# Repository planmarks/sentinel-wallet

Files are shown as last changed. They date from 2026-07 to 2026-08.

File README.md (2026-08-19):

<div align="center">

# 🛡️ Sentinel Hardware Wallet

### Your keys and coins kept offline, signed offline, on a device you hold in your hand.







*A pocket-sized, open-source cold wallet for 14 blockchains.*

</div>

---

> ⚠️ **Status:** Firmware version `1.0.0`. This is a hobbyist / educational hardware-wallet project,
> not a certified secure product. Please read the [Security Model & Honest Limitations](#-security-model--honest-limitations)
> section before storing meaningful funds.

---

## 📖 What It Is

A cold wallet keeps the secret keys that control your crypto **offline**, away from any
internet-connected computer. Sentinel follows that model:

- **Keys are born on the device.** A BIP39 recovery phrase (12/18/24 words) is generated from the
  chip's hardware random number generator — or you can restore an existing phrase.
- **Keys stay on the device.** The seed is encrypted and written to the chip's flash. It only ever
  exists in plaintext in RAM while the wallet is unlocked, and it's wiped from RAM the moment you lock.
- **The device only signs what you approve.** The companion app builds a transaction and sends it
  over. Sentinel shows you the recipients and the fee on its own screen, and it won't sign until you
  press and hold the confirm button.
- **It works air-gapped.** USB and Bluetooth are just transports for passing transaction data back
  and forth; the signing itself is fully offline, and Bluetooth is **off by default**.

**Hardware target:** Seeed XIAO ESP32-C5 · Arduino-ESP32 core 3.3.5+
**Display:** SSD1306/SSD1315 128×64 I²C OLED
**Interface:** 6 buttons (Up / Down / OK / Back / Left / Right), USB serial, optional BLE

---

## 🪙 Supported Cryptocurrencies

Sentinel supports a wide range of chains across multiple cryptographic families. Like a real
hardware wallet, **EVM chains and tokens all sign through a single "Ethereum" engine**, and SPL /
TRC-20 tokens sign through their parent chain — so the list of *assets* you can hold is much larger
than the list of on-device menu entries.

### Bitcoin & UTXO chains

| Coin | Ticker | Curve | Derivation | Address type |
|---|---|---|---|---|
| Bitcoin | BTC | secp256k1 | BIP84 `m/84'/0'` | Native SegWit (bech32) |
| Litecoin | LTC | secp256k1 | BIP84 `m/84'/2'` | Native SegWit (`ltc…`) |
| Dogecoin | DOGE | secp256k1 | BIP44 `m/44'/3'` | P2PKH |
| Dash | DASH | secp256k1 | BIP44 `m/44'/5'` | P2PKH |
| DigiByte | DGB | secp256k1 | BIP84 `m/84'/20'` | Native SegWit (`dgb…`) |
| Ravencoin | RVN | secp256k1 | BIP44 `m/44'/175'` | P2PKH |
| Bitcoin Cash | BCH | secp256k1 | `m/44'/145'` | CashAddr (SIGHASH_FORKID) |

Bitcoin (and other PSBT chains) support full **PSBT** signing with itemized output review.

### Ethereum & EVM chains

The **Ethereum** engine (`secp256k1`, BIP44 `m/44'/60'`, EIP-1559) signs for Ethereum **and every
EVM-compatible chain and ERC-20 token** the companion app knows about. The correct label is derived
from the transaction payload itself (chain ID for native transfers, contract address for tokens).

- **Ethereum (ETH)** and ERC-20 tokens such as **USDT** and **USDC**
- EVM chains routed through the same engine include:
  **BNB** Smart Chain, **Avalanche** (AVAX), **Polygon** (POL), **Base**, **Optimism** (OP),
  **Arbitrum** (ARB), **Cronos** (CRO), **Fantom** (FTM), **Ethereum Classic** (ETC), **Linea**,
  **Celo**, **Mantle** (MNT), **Flare** (FLR), **XDC**, **KuCoin Chain** (KCS), **X Layer** (OKB),
  **Filecoin EVM** (FILEVM), **BitTorrent Chain** (BTT), **IOTA EVM**, **Sonic** (S),
  **Kaia** (KAIA), **Hyperliquid** (HYPE), **Monad** (MON), and others (XTZ, XPL, M).

> New EVM chains and ERC-20 tokens generally need **no firmware change** — they're added on the app
> side, since they all share Ethereum's keys, addresses, and signing.

### Solana & SPL tokens

| Coin | Ticker | Curve | Derivation |
|---|---|---|---|
| Solana | SOL | ed25519 | SLIP-0010 `m/44'/501'` |

Solana transfers are decoded and itemized for review; **SPL tokens** sign through the same Solana
engine.

### Cosmos ecosystem

All Cosmos-SDK chains use `secp256k1`, `m/44'/118'`, and bech32 addresses (differing only by prefix):

| Coin | Ticker | Address prefix |
|---|---|---|
| Cosmos Hub | ATOM | `cosmos…` |
| dYdX | DYDX | `dydx…` |
| Axelar | AXL | `axelar…` |
| Babylon | BABY | `bbn…` |
| Celestia | TIA | `celestia…` |

### Other Layer-1 networks

| Coin | Ticker | Curve | Derivation | Notes |
|---|---|---|---|---|
| XRP Ledger | XRP | secp256k1 | `m/44'/144'` | base58check |
| Stellar | XLM | ed25519 | SLIP-0010 `m/44'/148'` | payments itemized |
| Cardano | ADA | BIP32-Ed25519 (Icarus) | `m/1852'/1815'` | Blake2b, staking support |
| Tron | TRX | secp256k1 | `m/44'/195'` | base58check (`T…`) |
| Tether on Tron | USDT (TRC-20) | secp256k1 | shares TRX address | |
| BitTorrent on Tron | BTT (TRC-20) | secp256k1 | shares TRX address | |
| Toncoin / Gram | TON | ed25519 | SLIP-10 `m/44'/607'` | v4R2 address |
| Polkadot | DOT | ed25519 | SLIP-10 `m/44'/354'` | SS58 address |
| Sui | SUI | ed25519 | SLIP-10 `m/44'/784'` | |
| Aptos | APT | ed25519 | SLIP-10 `m/44'/637'` | |
| NEAR Protocol | NEAR | ed25519 | SLIP-10 `m/44'/397'` | |
| Algorand | ALGO | ed25519 | SLIP-10 `m/44'/283'` | |
| Filecoin (native) | FIL | secp256k1 | `m/44'/461'` | `f1…` address |

> **Mainnet only.** This firmware deliberately does not support testnets.

---

## 🔒 Security Measures

Sentinel implements defense in depth across storage, key handling, transaction approval, and
connectivity.

### PIN & encrypted storage

- **PIN-gated unlock.** The device is locked at boot and requires a **4–8 digit PIN** to unlock.
- **Strong encryption at rest.** The seed (and optional passphrase) are stored with
  **AES-256-GCM** (authenticated encryption). The key is derived from your PIN using
  **PBKDF2-HMAC-SHA256 with 60,000 iterations** and a **random 16-byte salt** unique to each wallet.
  Each record also uses a random 12-byte IV, a 16-byte authentication tag, and associated data (AAD)
  binding — so tampered or corrupted ciphertext is rejected rather than mis-decrypted.
- **Anti-brute-force self-wipe.** After **5 wrong PIN attempts** the wallet **erases itself**.
  Crucially, the attempt counter is incremented **and persisted to flash *before* the PIN is
  checked**, so pulling power mid-attempt still "burns" the try — defeating power-cycle brute-force
  attacks.

### Key handling

- **Keys live in RAM only.** The decrypted seed exists in plaintext only while unlocked. On lock,
  auto-lock, or reset, all key material is **zeroized** (`mbedtls_platform_zeroize`), including
  temporary buffers, PIN buffers, and mnemonic strings after use.
- **Hardware RNG.** New seeds and cryptographic salts/IVs come from the ESP32-C5's hardware random
  number generator.
- **Optional BIP39 passphrase (25th word).** Adds a second secret on top of the seed, stored
  encrypted alongside it — enabling hidden-wallet style protection.
- **The recovery phrase is shown only on the OLED** — never printed to Serial or sent over BLE.
- **Auto-lock on inactivity.** After a configurable "Battery Saver" timeout, the device wipes keys
  from RAM, turns Bluetooth off, and returns to the PIN screen.

### Transaction safety

- **Offline signing.** Private keys never leave the device; the companion app never sees them. Only
  the *signed* transaction/PSBT is returned.
- **On-device review + hold-to-confirm.** Recipients and fees are shown on the device's own screen,
  and nothing is signed until you **press and hold** the confirm button. A compromised computer or
  app cannot make the device sign silently.
- **Blind-signing is off by default.** For chains whose transactions can't be fully decoded and
  itemized on-device, Sentinel **refuses to sign** unless you have explicitly enabled "Blind sign"
  for that specific coin in its settings — mirroring the blind-signing guard used by mainstream
  hardware wallets.

### Connectivity & privacy

- **Bluetooth is optional and off by default.** BLE is only a *transport* (a Nordic UART "serial
  over BLE" profile). The radio only comes up **after** the wallet is unlocked, a transaction sent
  over BLE **still** requires on-device confirmation, and BLE is torn down on lock.
- **No MAC-address tracking.** The device advertises a **random 16-bit ID** (generated once from the
  hardware RNG) instead of its factory Bluetooth MAC, so a passive scanner can't persistently track a
  specific physical unit.
- **Shoulder-surfing-resistant PIN pad.** The on-screen digit cursor starts on a **random** digit and
  jumps to a **new random** digit after each entry, so an onlooker can't infer digits by counting
  cursor movements. The PIN screen also dims when idle.

### Auditable, self-contained cryptography

All cryptographic primitives are vendored and run locally with **no network calls**:

- **TweetNaCl** — ed25519 signatures (Solana, Stellar, TON, DOT, Sui, Aptos, NEAR, Algorand)
- **SLIP-0010** — ed25519 hierarchical key derivation
- **BLAKE2b** — Cardano key derivation / hashing
- **uBitcoin** — secp256k1 keys, addresses, and PSBT signing
- **mbedTLS** — AES-256-GCM and PBKDF2 for storage encryption
- **qrcodegen** — offline QR code generation for receive addresses

---

## 🧭 How You Use It

1. **First boot:** create a **New Device** (generate a fresh recovery phrase) or **Restore** an
   existing 12/18/24-word phrase. Optionally add a passphrase. Set a PIN.
2. **Write down your recovery phrase** (shown only on the device screen) and store it safely offline.
3. **Receive:** pick a coin, view your address as text and a scannable **QR code**.
4. **Send:** the companion app builds a transaction and sends it over USB or BLE. Review the outputs
   and fee on the device, then **hold OK** to sign. The signed transaction goes back to the app to
   broadcast.
5. **Settings:** toggle Bluetooth, set the auto-lock timeout, change language, change PIN, per-coin
   blind-sign, uninstall coins, or reset the device.

---

## ⚖️ Security Model & Honest Limitations

To use this project responsibly, understand what it does **and doesn't** protect against:

- **No dedicated secure element.** The ESP32-C5 is a general-purpose microcontroller. Your keys are
  protected by **PIN-derived encryption + the 5-try self-wipe**, not by tamper-resistant secure-chip
  hardware. The strength of your protection therefore depends heavily on your **PIN choice** (and, for
  extra safety, a **passphrase**). A determined attacker with physical possession, lab equipment, and
  unlimited time is outside this design's threat model.
- **Blind signing carries risk.** Enabling blind-sign for a chain means you're trusting the
  transaction the app hands you, because the device can't fully decode it. Enable it only when you
  need it, and understand what you're approving.
- **You are your own backup.** There is no "forgot PIN" recovery. If you forget your PIN (self-wipe)
  or lose your device, **only your written recovery phrase can restore your funds.** Protect that
  phrase like the keys it is.
- **Hobbyist firmware.** This code has not undergone a formal third-party security audit. Review the
  source, and consider it experimental.

---

## 📂 Project Layout

- `coldwallet.ino` — main firmware: UI, menus, flows, command handling
- `config.h` — hardware pins, coin IDs, and derivation notes
- `store.cpp/.h` — encrypted NVS storage, PIN, self-wipe, settings
- `signer.cpp/.h` — PSBT loading, output review, signing
- `wallet.cpp/.h` — seed/entropy, BIP39, address derivation helpers
- `ble.cpp/.h` — optional Bluetooth (Nordic UART) transport
- Per-chain modules — `eth`, `sol`, `xlm`, `ada`, `xrp`, `cosmos`, `tron`, `ton`, `dot`, `sui`,
  `apt`, `near`, `algo`, `bch`, `fil`, `bnb`, etc.
- Vendored crypto — `tweetnacl`, `ed25519`, `slip10`, `blake2*`, `qrcodegen`

---

*Sentinel is provided as-is, for educational and personal use. Always verify addresses and
transaction details on the device screen before confirming.*

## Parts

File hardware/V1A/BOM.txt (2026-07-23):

1. Seeed Studio XIAO ESP32C5
2. 0.96" I2C OLED Display
3. Temporary tactile switches (2-6 units)

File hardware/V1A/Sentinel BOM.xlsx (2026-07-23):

Name | Mouser pt nr | Manufacturer nr | Type | Price per unit | Component link | Qty per unit | Total cost per unit | Total cost | Datasheet
PTS526SMG20SMTR21 LFS | PTS526SMG20SMTR21 LFS |  | Push button | 0.15 eur | https://www.mouser.ee/en/ProductDetail/CK/PTS526SMG20SMTR21-LFS?qs=MyNHzdoqoQLOqPcVU%2F1RhA%3D%3D | 6 | 0.9 eur |  | https://www.littelfuse.com/assetdocs/littelfuse-ck-tactile-pts526-series-datasheet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
XIAO ESP32C3 (or C5/C6) | 713-113991054 | 113991054 | MCU | 4.52 eur | https://www.mouser.ee/en/ProductDetail/Seeed-Studio/113991054?qs=3Rah4i%252BhyCHVBerMrpzCkw%3D%3D | 1 | 4.52 eur
0.96" OLED Display |  | SSD1306 | Display | 3.36 eur - 13 eur | https://www.aliexpress.com/item/1005008233113190.html?pdp_ext_f=%7B"order"%3A"232"%2C"eval"%3A"1"%2C"fromPage"%3A"search"%7D&pdp_npi=6%40dis%21EUR%213.28%213.27%21%21%2124.73%2124.70%21%402103973d17848192089776174e0ef4%2112000044337041777%21sea%21EE%210%21ABX%211%210%21n_tag%3A-29910%3Bd%3A554b218d%3Bm03_new_user%3A-29895&curPageLogUid=JXFxipJKf0lz&utparam-url=scene%3Asearch%7Cquery_from%3A%7Cx_object_id%3A1005008233113190%7C_p_origin_prod%3A | 1 | 3.36 eur - 13 eur
On-Off Switch Horisontal | 611-0S202011MA0QN1 | 0S202011MA0QN1 | On-Off Switch | 0.72 eur | https://www.mouser.ee/en/ProductDetail/CK/0S202011MA0QN1?qs=CScMml99RXPYt0g84JzONA%3D%3D | 1 | 0.72 eur |  | https://www.littelfuse.com/assetdocs/littelfuse-ck-slide-os-series-datasheet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
On-Off Switch Vertical | 611-0S102011MS2QN1 | 0S102011MS2QN1 | On-Off Switch | 0.62 eur | https://www.mouser.ee/en/ProductDetail/CK/0S102011MS2QN1?qs=xWNScUPc28o71osWFQSpZA%3D%3D | 1 | 0.62 eur |  | https://www.littelfuse.com/assetdocs/littelfuse-ck-slide-os-series-datasheet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
PCB |  |  | PCB | 2 eur - 3 eur |  | 1 | 2 eur - 3 eur

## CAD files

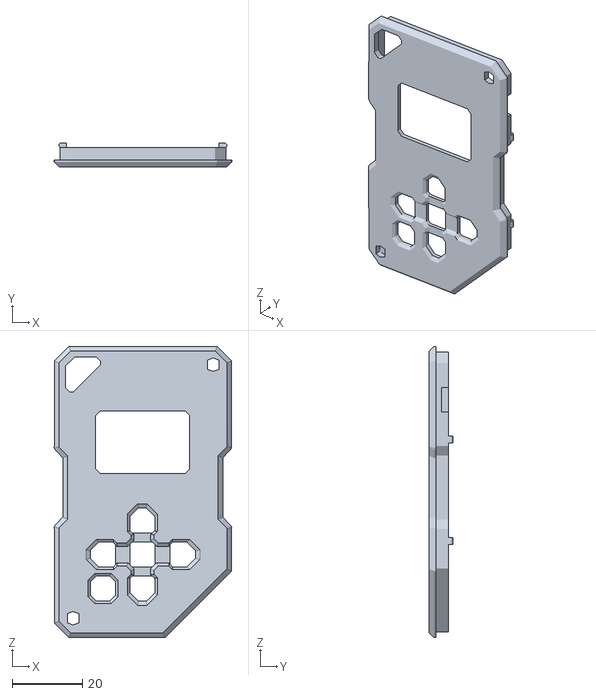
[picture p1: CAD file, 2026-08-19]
hardware/V1B/V1B/3D Models/Battery Case/V0/Sentinel-wallet-case-renderESP32C5_Cold_Wallet.007.stl
50.4 x 6.73 x 82.6

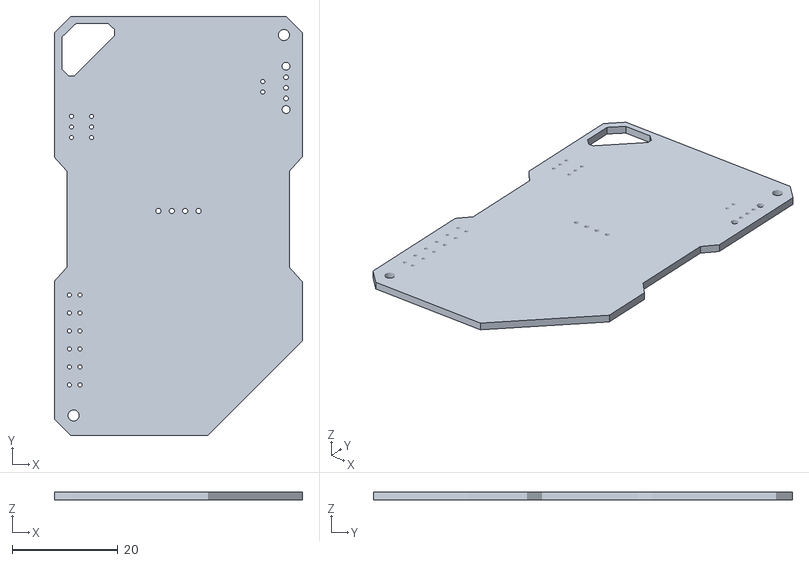
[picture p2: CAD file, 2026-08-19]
hardware/V1B/V1B/3D Models/ESP32C5 Cold Wallet.stl
47.0 x 79.3 x 1.51

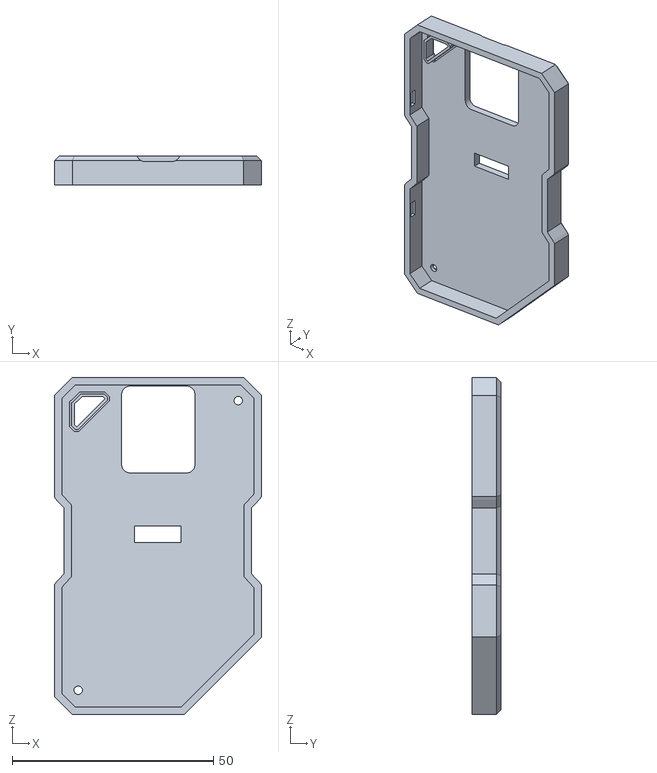
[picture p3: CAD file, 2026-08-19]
hardware/V1B/V1B/3D Models/SLIM Case/T3/Sentinel-wallet-case-renderSLIM_Case_Back.001.stl
51.5 x 7.30 x 83.8

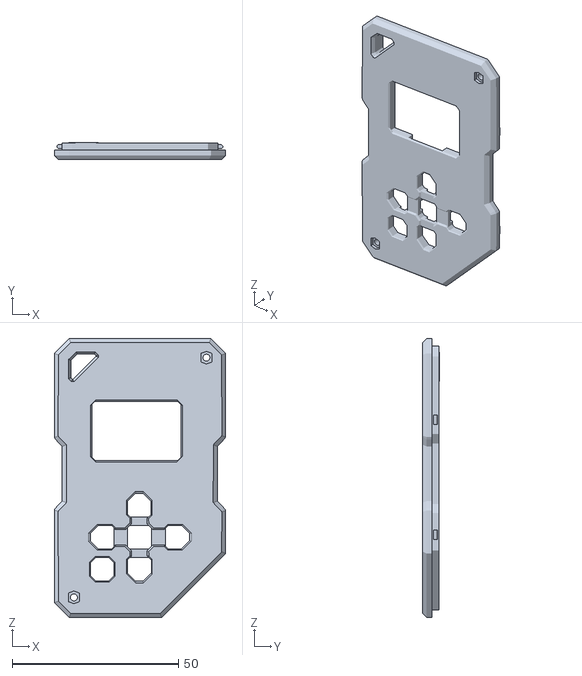
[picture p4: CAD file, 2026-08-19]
hardware/V1B/V1B/3D Models/SLIM Case/Test-SLIM_Case_Front.stl
51.5 x 4.99 x 83.8

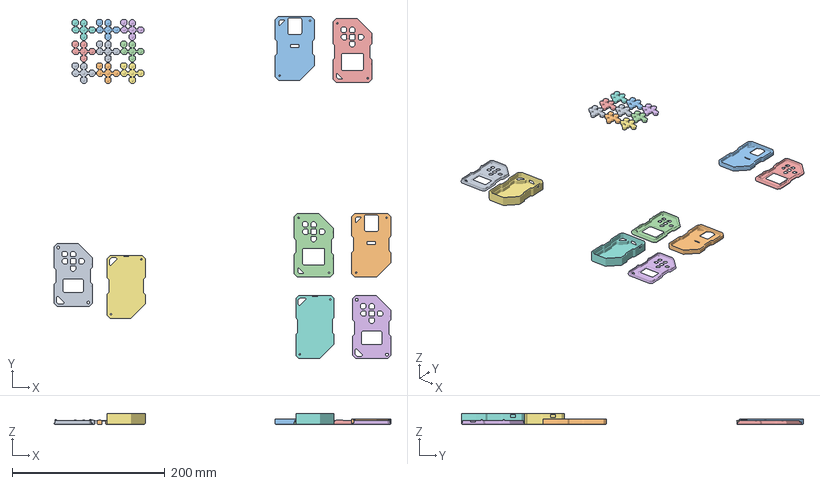
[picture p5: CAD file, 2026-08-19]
hardware/V1B/V1B/Case Sentinel V1B.3mf
441.7 x 448.5 x 14.6 mm
Sentinel-wallet-case-renderCube.001.stl x 9
Sentinel-wallet-case-renderSLIM_Case_Back.001.stl x 2
Sentinel-wallet-case-renderSLIM_Case_Front.001.stl x 2
Sentinel-wallet-case-renderESP32C5_Cold_Wallet.007.stl x 2
Sentinel-wallet-case-renderESP32C5_Cold_Wallet.001.stl x 2

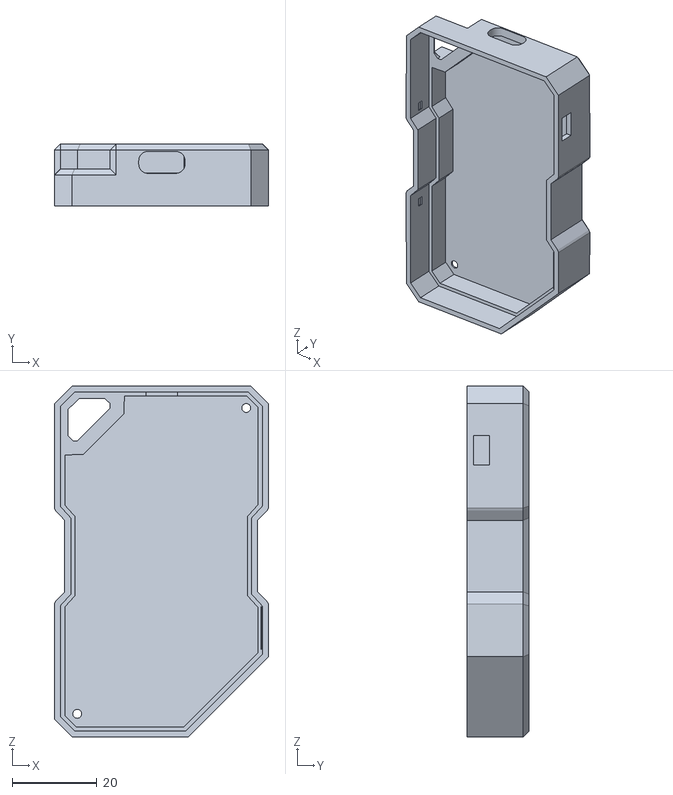
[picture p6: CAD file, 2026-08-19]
hardware/V1B/V1B/3D Models/Battery Case/V0/Sentinel-wallet-case-renderESP32C5_Cold_Wallet.001.stl
50.4 x 14.6 x 82.6

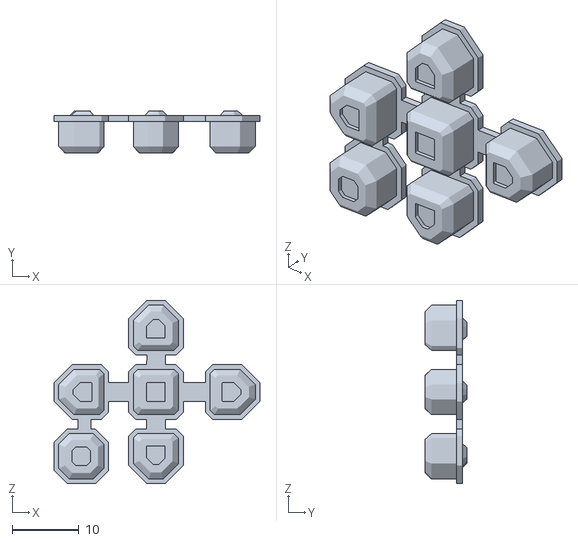
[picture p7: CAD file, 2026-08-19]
hardware/V1B/V1B/3D Models/SLIM Case/T3/Sentinel-wallet-case-renderCube.001.stl
30.8 x 6.22 x 27.4

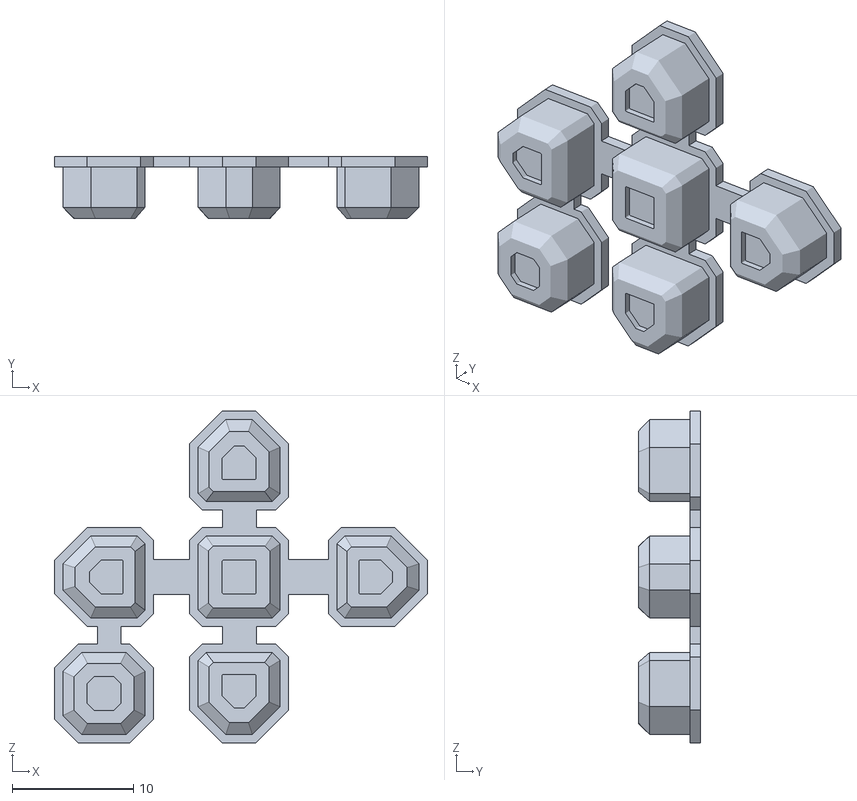
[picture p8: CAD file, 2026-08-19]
hardware/V1B/V1B/3D Models/SLIM Case/Test-Cube.011.stl
30.8 x 5.16 x 27.4

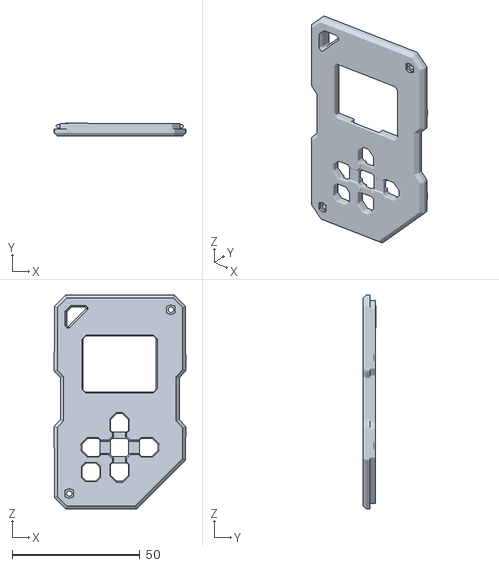
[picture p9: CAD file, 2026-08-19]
hardware/V1B/V1B/3D Models/SLIM Case/2TestSLIM_Case_Front.stl
51.5 x 4.99 x 83.8

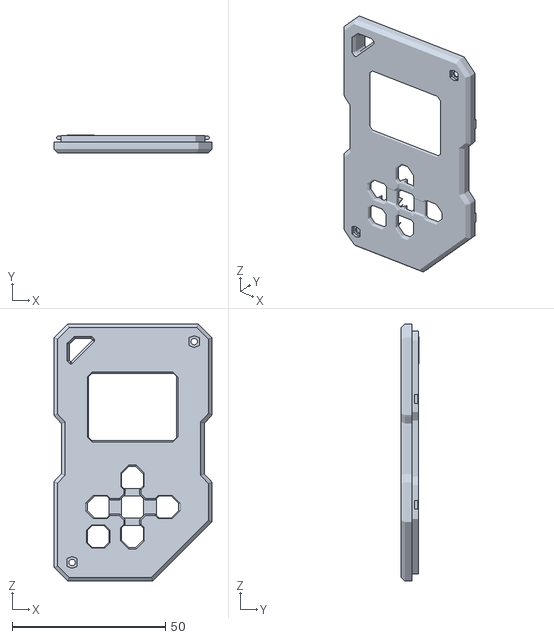
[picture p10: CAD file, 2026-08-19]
hardware/V1B/V1B/3D Models/SLIM Case/T3/Sentinel-wallet-case-renderSLIM_Case_Front.001.stl
51.5 x 5.74 x 83.8

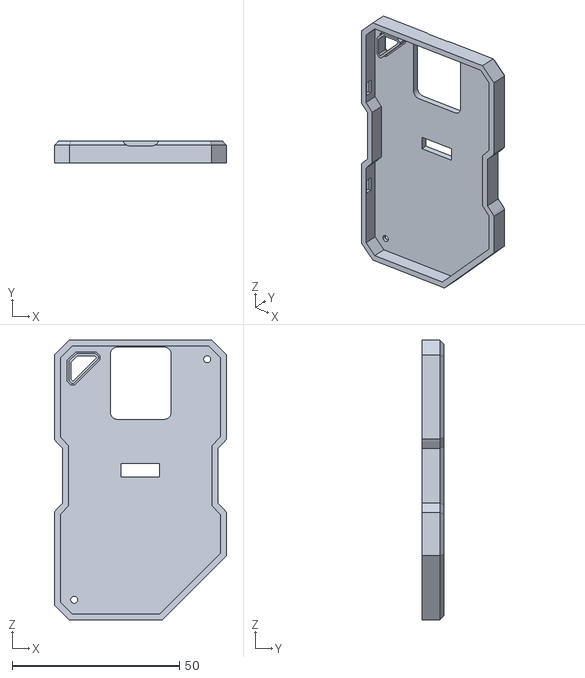
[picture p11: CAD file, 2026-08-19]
hardware/V1B/V1B/3D Models/SLIM Case/Test-SLIM_Case_Back.stl
51.5 x 6.55 x 83.8

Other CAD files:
hardware/V1B/V1B/3D Models/Sentinel-wallet-case-render.blend

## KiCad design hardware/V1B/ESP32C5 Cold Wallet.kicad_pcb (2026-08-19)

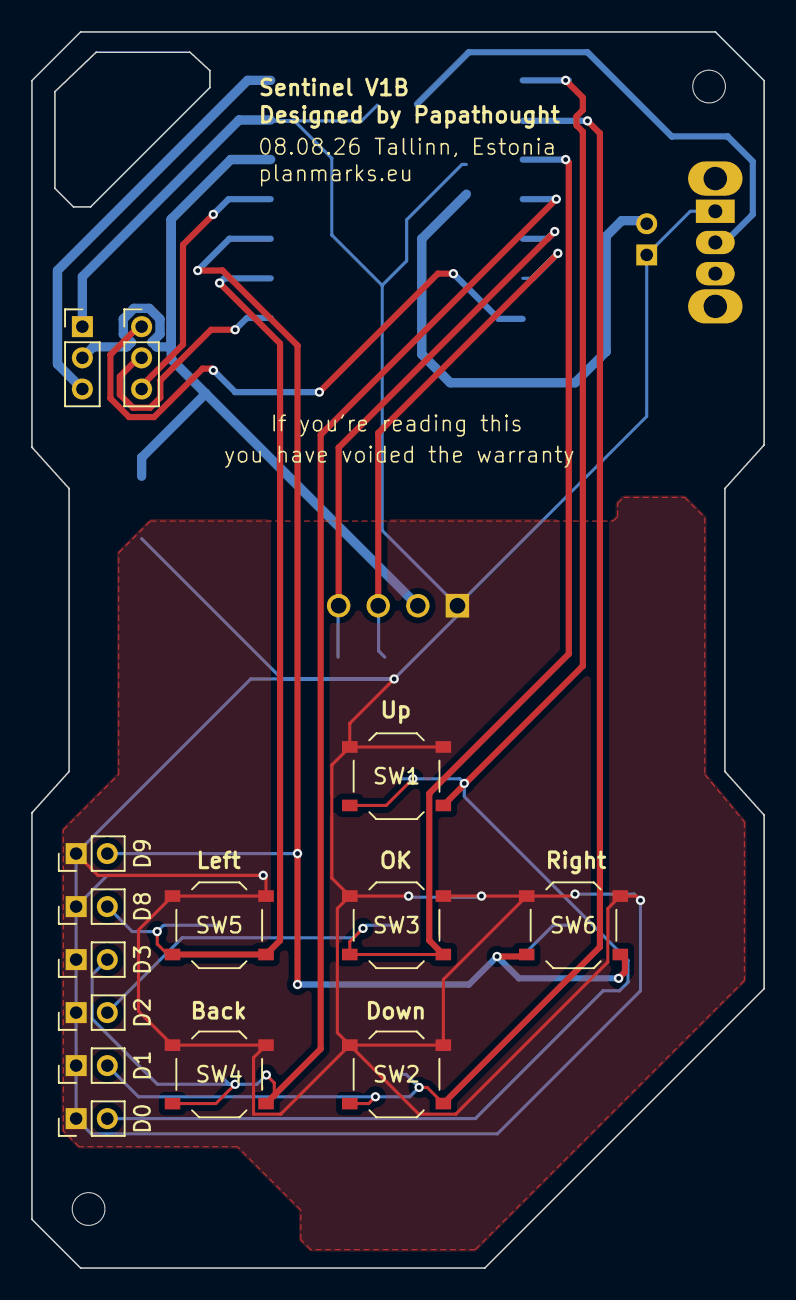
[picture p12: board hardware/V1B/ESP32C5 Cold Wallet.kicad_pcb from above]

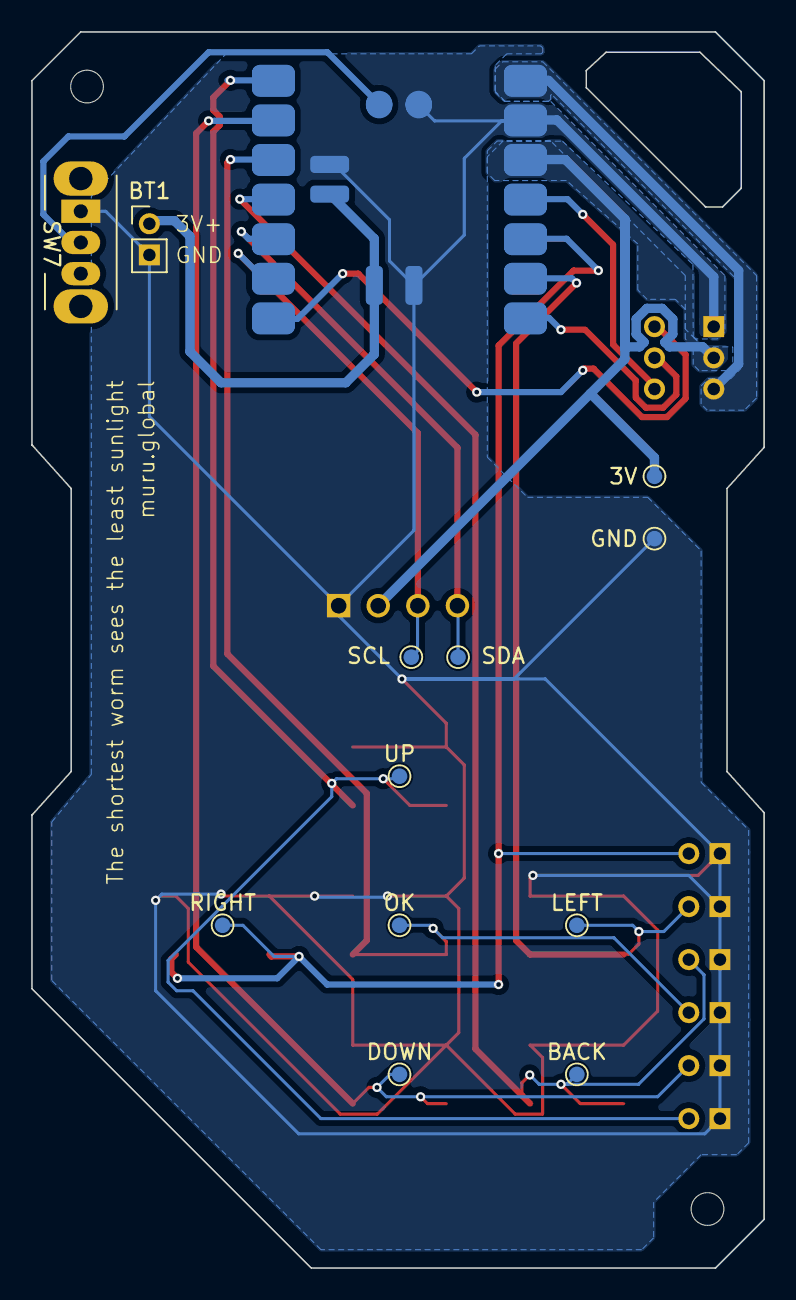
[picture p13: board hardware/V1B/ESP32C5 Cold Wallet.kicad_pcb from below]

Board: 2 copper layers, 47.0 x 79.3 mm, 29 parts (14 on the bottom side), 16 nets.

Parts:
3V: 3V3; TestPoint_Pad_D1.0mm
BACK: SW-BCK; TestPoint_Pad_D1.0mm
BT1: Battery; PinHeader_1x02_P2.00mm_Vertical
D0, D1, D2, D3, D8, D9: PinHeader_1x02_P2.00mm_Vertical
DOWN: SW-DWN; TestPoint_Pad_D1.0mm
GND: GND; TestPoint_Pad_D1.0mm
LEFT: SW-LFT; TestPoint_Pad_D1.0mm
MNT: MountingHole_2.1mm
MNT#2: MountingHole_2.1mm
OK: SW-OK; TestPoint_Pad_D1.0mm
RIGHT: SW-RHT; TestPoint_Pad_D1.0mm
SCL: SCL; TestPoint_Pad_D1.0mm
SDA: SDA; TestPoint_Pad_D1.0mm
SW1: SW_Push UP; SW_Push_1P1T_XKB_TS-1187A
SW2: SW_Push DOWN; SW_Push_1P1T_XKB_TS-1187A
SW3: SW_Push OK; SW_Push_1P1T_XKB_TS-1187A
SW4: SW_Push BACK; SW_Push_1P1T_XKB_TS-1187A
SW5: SW_Push LEFT; SW_Push_1P1T_XKB_TS-1187A
SW6: SW_Push RIGHT; SW_Push_1P1T_XKB_TS-1187A
SW7: SW_SPDT; SW_Slide_SPDT_Angled_CK_OS102011MA1Q
U1: XIAO-ESP32-C5-SMD
U2: DM-OLED096-636; MODULE_DM-OLED096-636
U3: XIAO-ESP32-C3-SMD
UP: SW-UP; TestPoint_Pad_D1.0mm

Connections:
+3.3V: 3V.1 (1_1), U1.12 (3V3_OUT), U2.2 (VCC_IN), U3.12 (3V3_OUT)
D0-SW1: D0.2, SW1.2, U1.1 (D0), U3.1 (D0), UP.1 (1_1)
D1-SW2: D1.2, DOWN.1 (1_1), SW2.2, U1.2 (D1), U3.2 (D1)
D2-SW3: D2.2, OK.1 (1_1), SW3.2, U1.3 (D2), U3.3 (D2)
D3-SW4: BACK.1 (1_1), D3.2, SW4.2, U1.4 (D3), U3.4 (D3)
D4-SDA: SDA.1 (1_1), U1.5 (D4), U2.4 (SDA), U3.5 (D4)
D5-SCL: SCL.1 (1_1), U1.6 (D5), U2.3 (SCL), U3.6 (D5)
D6: U1.7 (D6), U3.7 (D6)
D7: U1.8 (D7), U3.8 (D7)
D8-SW5: D8.2, LEFT.1 (1_1), SW5.2, U1.9 (D8), U3.9 (D8)
D9-SW6: D9.2, RIGHT.1 (1_1), SW6.2, U1.10 (D9), U3.10 (D9/BOOT)
D10: U1.11 (D10), U3.11 (D10)
EN: SW7.2 (B), U1.17 (EN), U3.17 (EN)
GND: BT1.2 (-), D0.1, D1.1, D2.1, D3.1, D8.1, D9.1, GND.1 (1_1), SW1.1, SW2.1, SW3.1, SW4.1, SW5.1, SW6.1, SW7.1 (A), U1.13 (GND), U1.18 (GND), U1.24 (GND), U2.1 (GND), U3.13 (GND), U3.18 (GND), U3.22 (GND)
VBAT: BT1.1 (+), U1.23 (VBAT), U3.21 (VBAT)
VBUS: U1.14 (VBUS), U3.14 (VBUS)

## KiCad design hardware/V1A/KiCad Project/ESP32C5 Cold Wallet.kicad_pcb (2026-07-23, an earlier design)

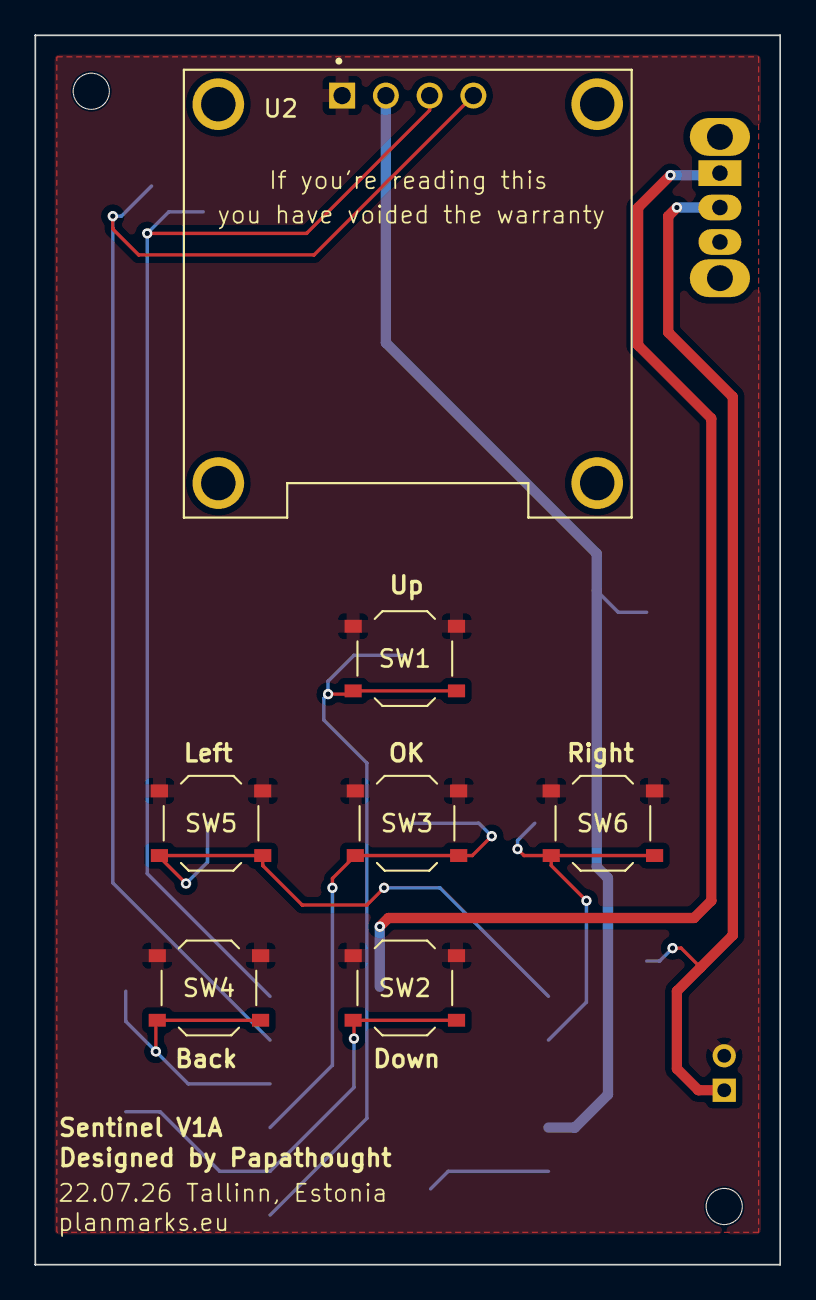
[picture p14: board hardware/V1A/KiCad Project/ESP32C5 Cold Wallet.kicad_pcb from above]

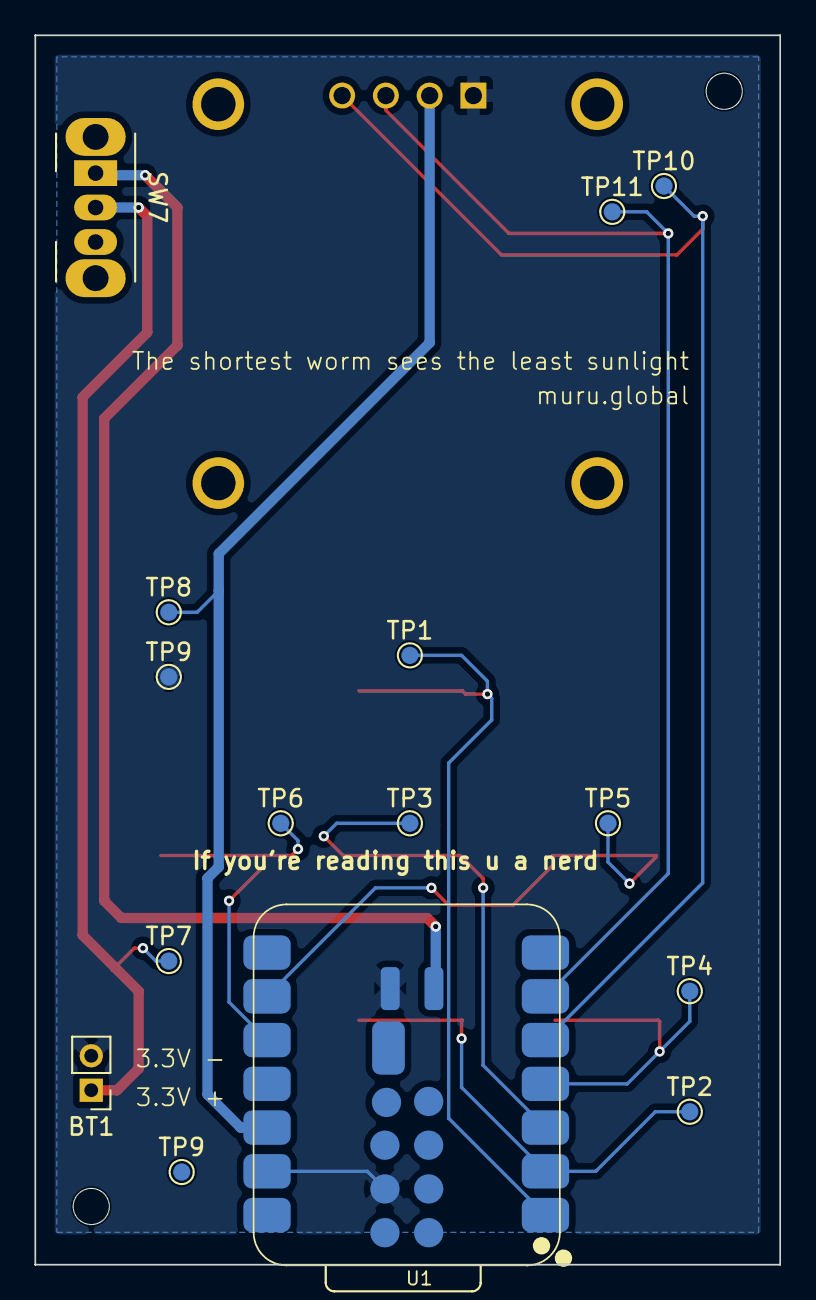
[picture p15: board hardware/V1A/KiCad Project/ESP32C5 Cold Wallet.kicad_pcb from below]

Board: 2 copper layers, 43.2 x 71.4 mm, 24 parts (15 on the bottom side), 12 nets.

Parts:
BT1: Battery; PinHeader_1x02_P2.00mm_Vertical
MNT: MountingHole_2.1mm
MNT#2: MountingHole_2.1mm
SW1: SW_Push UP; SW_Push_1P1T_XKB_TS-1187A
SW2: SW_Push DOWN; SW_Push_1P1T_XKB_TS-1187A
SW3: SW_Push OK; SW_Push_1P1T_XKB_TS-1187A
SW4: SW_Push BACK; SW_Push_1P1T_XKB_TS-1187A
SW5: SW_Push LEFT; SW_Push_1P1T_XKB_TS-1187A
SW6: SW_Push RIGHT; SW_Push_1P1T_XKB_TS-1187A
SW7: SW_SPDT; SW_Slide_SPDT_Angled_CK_OS102011MA1Q
TP1: SW-UP; TestPoint_Pad_D1.0mm
TP2: SW-DWN; TestPoint_Pad_D1.0mm
TP3: SW-OK; TestPoint_Pad_D1.0mm
TP4: SW-BCK; TestPoint_Pad_D1.0mm
TP5: SW-LFT; TestPoint_Pad_D1.0mm
TP6: SW-RHT; TestPoint_Pad_D1.0mm
TP7: BAT; TestPoint_Pad_D1.0mm
TP8: 3V3; TestPoint_Pad_D1.0mm
TP9, TP9#2: GND; TestPoint_Pad_D1.0mm
TP10: SDA; TestPoint_Pad_D1.0mm
TP11: SCL; TestPoint_Pad_D1.0mm
U1: XIAO-ESP32-C5-SMD
U2: DM-OLED096-636; MODULE_DM-OLED096-636

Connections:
+3.3V: TP8.1 (1_1), U1.12 (3V3_OUT), U2.2 (VCC_IN)
D0-SW1: SW1.2, TP1.1 (1_1), U1.1 (D0)
D1-SW2: SW2.2, TP2.1 (1_1), U1.2 (D1)
D2-SW3: SW3.2, TP3.1 (1_1), U1.3 (D2)
D3-SW4: SW4.2, TP4.1 (1_1), U1.4 (D3)
D4-SDA: TP10.1 (1_1), U1.5 (D4), U2.4 (SDA)
D5-SCL: TP11.1 (1_1), U1.6 (D5), U2.3 (SCL)
D8-SW5: SW5.2, TP5.1 (1_1), U1.9 (D8)
D9-SW6: SW6.2, TP6.1 (1_1), U1.10 (D9)
GND: BT1.2 (-), SW1.1, SW2.1, SW3.1, SW4.1, SW5.1, SW6.1, TP9#2.1 (1_1), U1.13 (GND), U1.18 (GND), U1.24 (GND), U2.1 (GND)
unnamed: BT1.1 (+), SW7.2 (B), TP7.1 (1_1)
VBAT: SW7.1 (A), U1.23 (VBAT)

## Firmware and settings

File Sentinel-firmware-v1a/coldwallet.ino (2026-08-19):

//
// Sentinel — Phase 6: optional BLE transport
//
// Cumulative features:
//  * BIP39 seed generation OR restore (enter an existing 12-word phrase via
//    letter-prefix autocomplete) — recovery after a wrong-PIN self-wipe.
//  * Optional BIP39 passphrase (25th word), stored encrypted with the seed.
//  * AES-256-GCM encrypted storage keyed by PBKDF2(PIN).
//  * Boot unlock; wrong-PIN self-wipe counter (survives power-cycle).
//  * Receive: BIP84 native-segwit addresses (m/84'/coin'/0'/0/i) as text + QR.
//  * Sign Tx: PSBT in over serial OR BLE, review outputs+fee on-device, hold
//    SELECT to confirm, device signs offline and returns the signed PSBT.
//  * Multi-coin: main-menu Coin cycles BTC / ETH / SOL / XLM / ADA, each with
//    receive + signing. ed25519 (SOL/XLM/ADA) via vendored TweetNaCl; Cardano
//    adds Icarus + BIP32-Ed25519 + Blake2b (vendored). ADA signing is blind-sign.
//  * Settings: coin, BLE on/off (default off), export xpub, wipe. Mainnet
//    only — this device line never supports testnet (removed 2026-08-09: a
//    stale isTestnet() NVS setting defaulted to testnet with no actual
//    on-device toggle ever wired up to change it, since setTestnet() was
//    never called from anywhere in this file).
//
// BLE is only a transport: a PSBT over BLE still needs on-device confirmation,
// and the radio only comes up after unlock. Secrets live only in RAM and are
// zeroized after use. The mnemonic is shown only on the OLED, never on Serial.
//
// Target: Seeed XIAO ESP32-C5  |  Arduino-ESP32 core 3.3.5+
// Requires libraries: U8g2, uBitcoin, NimBLE-Arduino (QRCode vendored as qrcodegen.*)
//
#include <nvs_flash.h>
#include <freertos/FreeRTOS.h>
#include <freertos/task.h>
#include "config.h"
#include "display.h"
#include "buttons.h"
#include "wallet.h"
#include "store.h"
#include "i18n.h"
#include "signer.h"
#include "ble.h"
#include "eth.h"
#include "bnb.h"
#include "xrp.h"
#include <Networks.h>
#include "sol.h"
#include "xlm.h"
#include "ada.h"
#include "cosmos.h"
#include "tron.h"
#include "ton.h"
#include "dot.h"
#include "sui.h"
#include "apt.h"
#include "near.h"
#include "algo.h"
#include "bch.h"
#include "fil.h"

// ESP-IDF sleep APIs for the low-power idle state (CPU light sleep + GPIO wake).
#include "esp_sleep.h"
#include "driver/gpio.h"
#include "esp_random.h"

// The default Arduino loop task stack (8 KB) is too small for the ed25519
// scalar multiplication (Solana/Stellar) on top of the UI/crypto call chain.
// Enlarge it so key derivation doesn't overflow the stack and reboot the device.
SET_LOOP_TASK_STACK_SIZE(24 * 1024);

// ---- Alt-UTXO network constants -------------------------------------------
// uBitcoin's Network struct: p2pkh, p2sh, bech32[5], wif,
//   xprv[4], yprv[4], zprv[4], Yprv[4], Zprv[4],
//   xpub[4], ypub[4], zpub[4], Ypub[4], Zpub[4], bip32 (coin type)

static const Network LtcMainnet = {
  0x30, 0x32, "ltc", 0xB0,
  {0x01,0x9D,0xA5,0x20}, {0x01,0xB8,0xC1,0x11}, {0x04,0xB2,0x43,0x0C},
  {0x02,0x95,0xB0,0x05}, {0x02,0xAA,0x7A,0x99},
  {0x01,0x9D,0xA4,0x62}, {0x01,0xB2,0x6E,0xF6}, {0x04,0xB2,0x47,0x46},
  {0x02,0x95,0xB4,0x3F}, {0x02,0xAA,0x7E,0xD3},
  2  // BIP44 coin type
};

static const Network DogeMainnet = {
  0x1E, 0x16, "", 0x9E,
  {0x02,0xFA,0xC3,0x98}, {0x02,0xFA,0xC3,0x98}, {0x02,0xFA,0xC3,0x98},
  {0x02,0xFA,0xC3,0x98}, {0x02,0xFA,0xC3,0x98},
  {0x02,0xFA,0xCA,0xFD}, {0x02,0xFA,0xCA,0xFD}, {0x02,0xFA,0xCA,0xFD},
  {0x02,0xFA,0xCA,0xFD}, {0x02,0xFA,0xCA,0xFD},
  3  // BIP44 coin type
};

// Params verified against Trezor's own coin registry (trezor-common defs/bitcoin/*.json).
static const Network DashMainnet = {
  0x4C, 0x10, "", 0xCC,
  {0x02,0xFE,0x52,0xF8}, {0x02,0xFE,0x52,0xF8}, {0x02,0xFE,0x52,0xF8},
  {0x02,0xFE,0x52,0xF8}, {0x02,0xFE,0x52,0xF8},
  {0x02,0xFE,0x52,0xCC}, {0x02,0xFE,0x52,0xCC}, {0x02,0xFE,0x52,0xCC},
  {0x02,0xFE,0x52,0xCC}, {0x02,0xFE,0x52,0xCC},
  5  // BIP44 coin type
};

static const Network DgbMainnet = {
  0x1E, 0x3F, "dgb", 0x9E,
  {0x04,0x88,0xAD,0xE4}, {0x04,0x9D,0x78,0x78}, {0x04,0xB2,0x43,0x0C},
  {0x04,0x9D,0x78,0x78}, {0x04,0xB2,0x43,0x0C},
  {0x04,0x88,0xB2,0x1E}, {0x04,0x9D,0x7C,0xB2}, {0x04,0xB2,0x47,0x46},
  {0x04,0x9D,0x7C,0xB2}, {0x04,0xB2,0x47,0x46},
  20  // BIP44 coin type
};

static const Network RvnMainnet = {
  0x3C, 0x7A, "", 0xBC,
  {0x04,0x88,0xAD,0xE4}, {0x04,0x88,0xAD,0xE4}, {0x04,0x88,0xAD,0xE4},
  {0x04,0x88,0xAD,0xE4}, {0x04,0x88,0xAD,0xE4},
  {0x04,0x88,0xB2,0x1E}, {0x04,0x88,0xB2,0x1E}, {0x04,0x88,0xB2,0x1E},
  {0x04,0x88,0xB2,0x1E}, {0x04,0x88,0xB2,0x1E},
  175  // BIP44 coin type
};

Display display;
Buttons  buttons;

// ---- Unlocked wallet state (RAM only) --------------------------------------
static uint8_t g_entropy[32];
static size_t  g_entropyLen = 0;
static char    g_passphrase[store::MAX_PASSPHRASE + 1] = {0};  // BIP39 passphrase (may be empty)
static bool    g_unlocked   = false;
static String  g_masterFp  = "";   // cached BIP32 fingerprint; cleared on lock

// Timestamp of the last user interaction (any button). Drives the inactivity
// auto-lock; updated wherever a button event is consumed.
static uint32_t g_lastActivityMs = 0;

static void lockWallet() {
  wallet::zeroize(g_entropy, sizeof(g_entropy));
  wallet::zeroize(g_passphrase, sizeof(g_passphrase));
  g_entropyLen = 0;
  g_unlocked   = false;
  g_masterFp   = "";
}

// ---- Menus ------------------------------------------------------------------
static const char *coinName(uint8_t c) {
  switch (c) {
    case COIN_ETH:  return "ETH";
    case COIN_XRP:  return "XRP";
    case COIN_DASH:   return "DASH";
    case COIN_DGB:    return "DGB";
    case COIN_RVN:    return "RVN";
    case COIN_TIA:    return "TIA";
    case COIN_ATOM: return "ATOM";
    case COIN_DYDX: return "DYDX";
    case COIN_AXL:  return "AXL";
    case COIN_BABY: return "BABY";
    case COIN_BCH:  return "BCH";
    case COIN_TRX:  return "TRX";
    case COIN_TON:  return "GRAM";
    case COIN_DOT:      return "DOT";
    case COIN_FIL:      return "FIL";
    case COIN_SUI:      return "SUI";
    case COIN_APT:      return "APT";
    case COIN_NEAR:     return "NEAR";
    case COIN_ALGO:     return "ALGO";
    case COIN_USDTTRX:  return "USDTTRX";
    case COIN_BTTTRX:   return "BTTTRX";
    case COIN_SOL:  return "SOL";
    case COIN_XLM:  return "XLM";
    case COIN_ADA:  return "ADA";
    case COIN_LTC:  return "LTC";
    case COIN_DOGE: return "DOGE";
    default:        return "BTC";
  }
}

static const char *coinDisplayName(uint8_t c) {
  switch (c) {
    case COIN_ETH:     return "Ethereum";
    case COIN_XRP:     return "Ripple";
    case COIN_DASH:   return "Dash";
    case COIN_DGB:    return "DigiByte";
    case COIN_RVN:    return "Ravencoin";
    case COIN_TIA:    return "Celestia";
    case COIN_ATOM:    return "Cosmos Hub";
    case COIN_DYDX:    return "dYdX";
    case COIN_AXL:     return "Axelar";
    case COIN_BABY:    return "Babylon";
    case COIN_BCH:     return "Bitcoin Cash";
    case COIN_TRX:     return "Tron";
    case COIN_TON:     return "Gram";
    case COIN_DOT:     return "Polkadot";
    case COIN_FIL:     return "Filecoin";
    case COIN_SUI:     return "Sui";
    case COIN_APT:     return "Aptos";
    case COIN_NEAR:    return "NEAR Protocol";
    case COIN_ALGO:    return "Algorand";
    case COIN_USDTTRX: return "USDT (TRC20)";
    case COIN_BTTTRX:  return "BTT (TRC20)";
    case COIN_SOL:     return "Solana";
    case COIN_XLM:     return "Stellar";
    case COIN_ADA:     return "Cardano";
    case COIN_LTC:     return "Litecoin";
    case COIN_DOGE:    return "Dogecoin";
    default:           return "Bitcoin";
  }
}

// EVM chains all share Ethereum's key/address and EIP-1559 signing (eth.cpp);
// only the chainId (carried in the tx line) differs. Every EVM chain and
// every ERC-20 token now signs through this one slot — see the note atop
// config.h for why none of them get their own COIN_* id anymore.
static bool isEvmCoin(uint8_t c) {
  return c == COIN_ETH;
}

// SPL tokens would share Solana's keypair/address and message-signing
// (sol.cpp) the same way ERC-20 tokens share isEvmCoin() — no ERC-20/BEP-20
// or SPL token gets its own COIN_* id; a token transfer signs through its
// native chain's signer, which decodes the transfer generically from the
// transaction bytes for display. See eth::txIsErc20()/txSymbol().
static bool isSolFamily(uint8_t c) {
  return c == COIN_SOL;
}

// Display label for a coin — TRC-20 variants show the parent symbol so the menu
// only says "USDT" / "USDC"; the network is shown separately in the picker.
static const char* coinLabel(uint8_t c) {
  if (c == COIN_USDTTRX) return "USDT";
  if (c == COIN_BTTTRX) return "BTT";
  return coinName(c);
}

// Map a symbol string (sent by the app) to its COIN_* constant. Every EVM
// leaf chain (BNB, AVAX, ...) and ERC-20 token (USDT, USDC, ...) the app may
// still ask for by name maps to COIN_ETH — same key/address, and eth.cpp
// derives the correct wire response label from the payload itself (see
// eth::txSignLabel()), not from which coin this resolves to.
static uint8_t coinFromSymbol(const String& sym) {
  if (sym == "BTC")     return COIN_BTC;
  if (sym == "ETH" || sym == "BNB" || sym == "USDT" || sym == "USDC" ||
      sym == "AVAX" || sym == "BASE" || sym == "POL" || sym == "CRO" ||
      sym == "OP" || sym == "ARB" || sym == "FTM" || sym == "ETC" ||
      sym == "LINEA" || sym == "CELO" || sym == "MNT" || sym == "HYPE" ||
      sym == "OKB" || sym == "KCS" || sym == "XDC" || sym == "FLR" ||
      sym == "FILEVM" || sym == "BTT" || sym == "MON" || sym == "XTZ" ||
      sym == "IOTA" || sym == "S" || sym == "XPL" || sym == "KAIA" ||
      sym == "M")
    return COIN_ETH;
  if (sym == "SOL")     return COIN_SOL;
  if (sym == "XRP")     return COIN_XRP;
  if (sym == "ADA")     return COIN_ADA;
  if (sym == "XLM")     return COIN_XLM;
  if (sym == "ATOM")    return COIN_ATOM;
  if (sym == "DYDX")    return COIN_DYDX;
  if (sym == "AXL")     return COIN_AXL;
  if (sym == "BABY")    return COIN_BABY;
  if (sym == "BCH")     return COIN_BCH;
  if (sym == "TRX")     return COIN_TRX;
  if (sym == "GRAM")    return COIN_TON;
  if (sym == "DOT")     return COIN_DOT;
  if (sym == "FIL")     return COIN_FIL;
  if (sym == "SUI")     return COIN_SUI;
  if (sym == "APT")     return COIN_APT;
  if (sym == "NEAR")    return COIN_NEAR;
  if (sym == "ALGO")    return COIN_ALGO;
  if (sym == "USDTTRX") return COIN_USDTTRX;
  if (sym == "BTTTRX") return COIN_BTTTRX;
  if (sym == "LTC")     return COIN_LTC;
  if (sym == "DOGE")    return COIN_DOGE;
  if (sym == "DASH")   return COIN_DASH;
  if (sym == "DGB")    return COIN_DGB;
  if (sym == "RVN")    return COIN_RVN;
  if (sym == "TIA")    return COIN_TIA;
  return COIN_BTC;
}

// Advance / retreat through active coins only.
// Returns current coin unchanged if no other active coin exists.
static uint8_t nextCoin(uint8_t c) {
  uint8_t orig = c;
  do {
    c = (c + 1) % COIN_COUNT;
    if (c == orig) return c;
  } while (!store::isCoinActive(c));
  return c;
}
static uint8_t prevCoin(uint8_t c) {
  uint8_t orig = c;
  do {
    c = (uint8_t)((c + COIN_COUNT - 1) % COIN_COUNT);
    if (c == orig) return c;
  } while (!store::isCoinActive(c));
  return c;
}

// Settings menu: Bluetooth toggle, Battery Saver, Language, Device
// Information, Uninstall All Coins, Change PIN, Reset Device. Bluetooth is
// drawn as an animated switch graphic (Display::settingsMenu), not
// "ON"/"OFF" text; the rest are plain action rows that open their own
// sub-screen or modal.
static const uint8_t kSettingsCount = 7;
static Display::SettingsRow settingsRows[kSettingsCount];
static void buildSettings() {
  uint8_t lg = store::language();
  settingsRows[0] = { "Bluetooth", true, store::bleEnabled() };   // brand name - never translated
  settingsRows[1] = { i18n::tr(lg, i18n::S_BATTERY_SAVER), false, false };
  settingsRows[2] = { i18n::tr(lg, i18n::S_LANGUAGE), false, false };
  settingsRows[3] = { i18n::tr(lg, i18n::S_DEVICE_INFORMATION), false, false };
  settingsRows[4] = { i18n::tr(lg, i18n::S_UNINSTALL_ALL_COINS), false, false };
  settingsRows[5] = { i18n::tr(lg, i18n::S_CHANGE_PIN), false, false };
  settingsRows[6] = { i18n::tr(lg, i18n::S_RESET_DEVICE), false, false };
}

// ---- Battery Saver picker (Off/1/3/5/10 min) --------------------------------
static const uint8_t kBatterySaverCount = 5;
static const char *  kBatterySaverLabels[kBatterySaverCount];   // filled by buildBatterySaverLabels()
static const uint8_t kBatterySaverMinutes[kBatterySaverCount] = { 0, 1, 3, 5, 10 };
static uint8_t     g_batterySaverSel = 0;

static void buildBatterySaverLabels() {
  uint8_t lg = store::language();
  kBatterySaverLabels[0] = i18n::tr(lg, i18n::S_OFF);
  kBatterySaverLabels[1] = i18n::tr(lg, i18n::S_1_MINUTE);
  kBatterySaverLabels[2] = i18n::tr(lg, i18n::S_3_MINUTES);
  kBatterySaverLabels[3] = i18n::tr(lg, i18n::S_5_MINUTES);
  kBatterySaverLabels[4] = i18n::tr(lg, i18n::S_10_MINUTES);
}

// ---- Language picker --------------------------------------------------------
// Only the 5 languages i18n.cpp actually has translations for - the other 6
// the app/landing site offer (Vietnamese, Hindi, Arabic, Korean, Japanese,
// Chinese) need either a script-shaping engine (Arabic/Hindi) or a full
// bigger-glyph layout rework (Vietnamese/Korean/Japanese/Chinese) the OLED
// firmware doesn't have yet - see i18n.h. English names, not native scripts.
static const uint8_t kLanguageCount = i18n::LANG_SUPPORTED_COUNT;
static const char *const kLanguageLabels[kLanguageCount] = {
  "English", "Spanish", "Portuguese", "Estonian", "Russian"
};
static uint8_t     g_languageSel = 0;

// ---- Device Information -----------------------------------------------------
// Static (not stack-local) — Display::message() stores the body pointer and
// re-reads it on every redraw while this screen is showing, so it must
// outlive the function that formats it.
static char deviceInfoBody[80];
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
void loop() {
  // Auto-lock: after AUTO_LOCK_MS with no interaction, re-lock and return to the
  // PIN screen (BLE is turned off inside autoLock). Unsigned subtraction handles
  // millis() rollover correctly.
  if (g_unlocked && (uint32_t)(millis() - g_lastActivityMs) >= autoLockMs()) {
    autoLock();
    return;
  }

  // Accept BLE commands. PAIR is handled regardless of lock state — the
  // physical button confirmation on the device is the security mechanism.
  // Transaction signing is only allowed while unlocked at the menu.
  if (ble::isConnected()) {
    String line;
    if (ble::takePsbt(line)) {

      if (line.startsWith("PAIR|")) {
        // PIN pairing — app generates the code, shows it to the user, sends it
        // here. We display it on-screen so the user can compare, then confirm
        // or reject with a long-press of OK / any other button.
        String code = line.substring(5);
        char body[48];
        snprintf(body, sizeof(body), "Code: %s\nHold OK: pair\nBack: reject", code.c_str());
        display.message("Pair request", body);
        ButtonAction a = waitButton();
        if (a.id == BTN_SELECT && a.event == EV_LONGPRESS) {
          ble::sendLine("PAIR-OK>");
          display.message("Paired!", "Sentinel linked");
          delay(800);
        } else {
          ble::sendLine("PAIR-FAIL>");
          display.message("Pair", "Rejected");
          delay(800);
        }
        render();
        return;
      }

      // App-initiated address generation (any screen, unlocked).
      if (g_unlocked && line.startsWith("ADDR_REQ|")) {
        g_lastActivityMs = millis();
        handleAddrReq(line.substring(9));
        // Real bug this fixes: unlike every other handler in this dispatch
        // (the Serial equivalent falls through to its own render() call;
        // COIN_REMOVE/PAIR above call it explicitly), this one returned
        // immediately after handleAddrReq() with no render() at all — so
        // the loading screen's final 100% frame just stayed on-screen
        // forever instead of the normal screen (menu/receive/etc.) resuming.
        render();
        return;
      }

      // Silent probe for account discovery — no activateCoin(), no screen change.
      if (g_unlocked && line.startsWith("ADDR_PROBE|")) {
        // Was missing from every other authenticated command's pattern —
        // a real multi-round-trip discovery scan (dozens of probes in a
        // row) never counted as activity, so it could run right into the
        // auto-lock timer firing mid-scan and killing the connection.
        g_lastActivityMs = millis();
        handleAddrProbe(line.substring(11));
        return;
      }

      if (g_unlocked && line.startsWith("SIGN_SELECT|")) {
        g_lastActivityMs = millis();
        g_signSelectSource = SRC_BLE;
        handleSignSelect(line.substring(12));
        render();
        return;
      }

      if (g_unlocked && line.startsWith("ACCT_DELETE|")) {
        handleAcctDelete(line.substring(12));
        return;
      }

      if (g_unlocked && line.startsWith("COIN_REMOVE|")) {
        handleCoinDeactivate(line.substring(12));
        render();
        return;
      }

      if (g_unlocked && line.startsWith("ACCT_RENAME|")) {
        handleAcctRename(line.substring(12));
        return;
      }

      if (g_unlocked && line.startsWith("ACCT_SYNC|")) {
        handleAcctSync(line.substring(10));
        return;
      }

      if (g_unlocked && line == "SYNC_REQ") {
        g_lastActivityMs = millis();
        handleSyncReq();
        render();
        return;
      }

      if (g_unlocked && line.startsWith("XPUB_REQ|")) {
        g_lastActivityMs = millis();
        handleXpubReq(line.substring(9));
        return;
      }

      if (line == "HELLO") {
        if (g_unlocked) { g_lastActivityMs = millis(); notifyReady(); }
        return;
      }

      if (g_unlocked && screen == SCREEN_MENU) {
        g_lastActivityMs = millis();
        uint8_t c = store::coin();
        if (isEvmCoin(c)) {
          if (eth::loadTx(line)) { g_signSource = SRC_BLE; g_signPage = 0; screen = SCREEN_SIGN_REVIEW; }
        } else if (c == COIN_XRP) {
          if (xrp::loadTx(line)) { g_signSource = SRC_BLE; g_signPage = 0; screen = SCREEN_SIGN_REVIEW; }
        } else if (c == COIN_ATOM) {
          if (cosmos::loadTx(line, "ATOM")) { g_signSource = SRC_BLE; g_signPage = 0; screen = SCREEN_SIGN_REVIEW; }
        } else if (c == COIN_DYDX) {
          if (cosmos::loadTx(line, "DYDX")) { g_signSource = SRC_BLE; g_signPage = 0; screen = SCREEN_SIGN_REVIEW; }
        } else if (c == COIN_AXL) {
          if (cosmos::loadTx(line, "AXL")) { g_signSource = SRC_BLE; g_signPage = 0; screen = SCREEN_SIGN_REVIEW; }
        } else if (c == COIN_BABY) {
          if (cosmos::loadTx(line, "BABY")) { g_signSource = SRC_BLE; g_signPage = 0; screen = SCREEN_SIGN_REVIEW; }
        } else if (c == COIN_TIA) {
          if (cosmos::loadTx(line, "TIA")) { g_signSource = SRC_BLE; g_signPage = 0; screen = SCREEN_SIGN_REVIEW; }
        } else if (c == COIN_TRX) {
          if (tron::loadTx(line)) { g_signSource = SRC_BLE; g_signPage = 0; screen = SCREEN_SIGN_REVIEW; }
        } else if (c == COIN_TON) {
          if (ton::loadTx(line)) { g_signSource = SRC_BLE; g_signPage = 0; screen = SCREEN_SIGN_REVIEW; }
        } else if (c == COIN_DOT) {
          if (dot::loadTx(line)) { g_signSource = SRC_BLE; g_signPage = 0; screen = SCREEN_SIGN_REVIEW; }
        } else if (c == COIN_FIL) {
          if (fil::loadTx(line)) { g_signSource = SRC_BLE; g_signPage = 0; screen = SCREEN_SIGN_REVIEW; }
        } else if (c == COIN_SUI) {
          if (sui::loadTx(line)) { g_signSource = SRC_BLE; g_signPage = 0; screen = SCREEN_SIGN_REVIEW; }
        } else if (c == COIN_APT) {
          if (apt::loadTx(line)) { g_signSource = SRC_BLE; g_signPage = 0; screen = SCREEN_SIGN_REVIEW; }
        } else if (c == COIN_NEAR) {
          if (near::loadTx(line)) { g_signSource = SRC_BLE; g_signPage = 0; screen = SCREEN_SIGN_REVIEW; }
        } else if (c == COIN_ALGO) {
          if (algo::loadTx(line)) { g_signSource = SRC_BLE; g_signPage = 0; screen = SCREEN_SIGN_REVIEW; }
        } else if (c == COIN_BCH) {
          if (bch::loadTx(line)) { g_signSource = SRC_BLE; g_signPage = 0; screen = SCREEN_SIGN_REVIEW; }
        } else if (c == COIN_USDTTRX || c == COIN_BTTTRX) {
          if (tron::loadTxForTag(String(coinName(c)), line)) { g_signSource = SRC_BLE; g_signPage = 0; screen = SCREEN_SIGN_REVIEW; }
        } else if (isSolFamily(c)) {
          if (sol::loadTx(line)) { g_signSource = SRC_BLE; g_signPage = 0; screen = SCREEN_SIGN_REVIEW; }
        } else if (c == COIN_XLM) {
          if (xlm::loadTx(line)) { g_signSource = SRC_BLE; g_signPage = 0; screen = SCREEN_SIGN_REVIEW; }
        } else if (c == COIN_ADA) {
          if (ada::loadTx(line)) { g_signSource = SRC_BLE; g_signPage = 0; screen = SCREEN_SIGN_REVIEW; }
        } else if (c == COIN_BTC) {
          // All PSBTs base64-encode to strings starting with "cHNidP" (magic psbt\xff).
          // Silently ignore anything else to prevent stray BLE lines triggering this path.
          if (line.startsWith("cHNidP")) startSignFromB64(line, SRC_BLE);
        } else if (c == COIN_LTC) {
          if (line.startsWith("cHNidP")) startSignFromB64(line, SRC_BLE, &LtcMainnet);
        } else if (c == COIN_DOGE) {
          if (line.startsWith("cHNidP")) startSignFromB64(line, SRC_BLE, &DogeMainnet);
        } else if (c == COIN_DASH) {
          if (line.startsWith("cHNidP")) startSignFromB64(line, SRC_BLE, &DashMainnet);
        } else if (c == COIN_DGB) {
          if (line.startsWith("cHNidP")) startSignFromB64(line, SRC_BLE, &DgbMainnet);
        } else if (c == COIN_RVN) {
          if (line.startsWith("cHNidP")) startSignFromB64(line, SRC_BLE, &RvnMainnet);
        }
        render();
      }
      return;
    }
  }
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

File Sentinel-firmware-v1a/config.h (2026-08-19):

#pragma once
//
// Sentinel — hardware configuration for the Seeed XIAO ESP32-C5
//
// Keep ALL board-specific pin and geometry constants here so the rest of the
// firmware stays hardware-agnostic.

// ---- Firmware identity ------------------------------------------------------
#define FW_NAME    "Sentinel"
#define FW_VERSION "1.0.0"

// ---- Serial -----------------------------------------------------------------
#define SERIAL_BAUD 115200

// ---- OLED (SSD1306, I2C) ----------------------------------------------------
// The XIAO form factor exposes the default I2C bus on SDA=D4, SCL=D5, so
// Wire.begin() needs no arguments. U8g2 uses the 8-bit form of the address.
#define OLED_WIDTH      128
#define OLED_HEIGHT     64
#define OLED_I2C_ADDR7  0x3C            // 7-bit; most 0.96" modules use 0x3C
#define OLED_I2C_ADDR8  (OLED_I2C_ADDR7 << 1)

// ---- Buttons ----------------------------------------------------------------
// Wired between GPIO and GND; internal pull-ups make them active-LOW.
// NOTE: if any of these is a strapping pin on the C5, move it to a free GPIO
// and update the mapping here (see Seeed pin-multiplexing wiki).
#define PIN_BTN_UP      D0
#define PIN_BTN_DOWN    D1
#define PIN_BTN_SELECT  D2   // "OK"
#define PIN_BTN_BACK    D3   // "Back/Del"
#define PIN_BTN_LEFT    D8   // Left  — advances the coin picker (GPIO8, not a strapping pin)
#define PIN_BTN_RIGHT   D9   // Right — steps the coin picker back (GPIO9, not a strapping pin)

// ---- Button timing (ms) -----------------------------------------------------
#define BTN_DEBOUNCE_MS    25
#define BTN_LONGPRESS_MS   700
#define BTN_REPEAT_MS      180   // auto-repeat interval while held (Up/Down)

// ---- Auto-lock --------------------------------------------------------------
// After this long with no button interaction, the device re-locks (wipes keys
// from RAM, turns BLE off) and returns to the PIN screen.
#define AUTO_LOCK_MS       (3UL * 60UL * 1000UL)   // 3 minutes

// ---- PIN & encrypted storage (Phase 3) --------------------------------------
#define PIN_MIN_DIGITS     4
#define PIN_MAX_DIGITS     8
#define PIN_MAX_TRIES      5     // wrong attempts before the wallet self-wipes
#define PBKDF2_ITERS       60000 // KDF cost; tune for the C5 unlock latency
#define NVS_NAMESPACE      "cw"  // NVS namespace for wallet blobs

// ---- BLE (Phase 6, optional, default OFF) -----------------------------------
// Nordic UART Service (NUS) — a de-facto "serial over BLE" profile supported by
// generic BLE terminal apps, so the PSBT flow works over BLE with no custom app.
#define BLE_DEVICE_NAME       "Sentinel Core+"
#define BLE_NUS_SERVICE_UUID  "6E400001-B5A3-F393-E0A9-E50E24DCCA9E"
#define BLE_NUS_RX_UUID       "6E400002-B5A3-F393-E0A9-E50E24DCCA9E"  // client -> device (write)
#define BLE_NUS_TX_UUID       "6E400003-B5A3-F393-E0A9-E50E24DCCA9E"  // device -> client (notify)

// Where a signed PSBT should be returned. Defined here (not in the .ino) so the
// type is known before the Arduino IDE's auto-generated function prototypes.
enum SignSource { SRC_SERIAL, SRC_BLE };
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

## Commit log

2026-07-23 Sentinel Wallet V1A Hardware
    Sentinel Hardware Crypto Wallet V1A Hardware schematics, BOM, KiCad project and Gerber files.
    SMD XIAO ESP32C5 can be replaced with SMD XIAO ESP32C3 and C6.
    [ESP32C5 Cold Wallet-B_Cu.gbr, ESP32C5 Cold Wallet-B_Mask.gbr, ESP32C5 Cold Wallet-B_Paste.gbr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]
2026-08-19 V1B files
    [2TestSLIM_Case_Front.stl, Case Sentinel V1B.3mf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]
